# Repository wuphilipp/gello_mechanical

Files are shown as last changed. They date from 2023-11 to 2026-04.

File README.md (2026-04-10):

# GELLO Mechanical
This is the central repo that holds the mechanical parts for GELLO. See the [website](https://wuphilipp.github.io/gello_site/) for the paper and other resources for GELLO.

If you have already built your GELLO, please see the [gello_software repo](https://github.com/wuphilipp/gello_software) for software setup and usage.

## Organization
Currently we support 7 robot types. The 3 from the original paper:
 * Franka FER (from Franka Robotics)
 * UR5 (from Universal Robotics)
 * xArm7 (from uFactory)

And 3 from community contributions:
 * YAM (from I2RT). Contributed by [Jeffrey Liu](https://github.com/jyliu24) and [Hardik Maheshwari](https://github.com/hmahesh007).
 * Lite6 (from uFactory). The lite6 design is contributed from [EL2031watson](https://twitter.com/EL2031watson). See the instructions [here](./lite6/README.md).
 * AR4 (from [Annin Robotics](https://www.anninrobotics.com/)) contributed by [@adob](https://github.com/adob). See instructions [here](./ar4/README.md).
 * FR3 and FR3 Duo (from and contributed by [Franka Robotics](https://franka.de)). See instructions [here](./franka_fr3/README.md)

Each robot has its own folder, with its own robot specific parts. The gripper files are in its own folder, which is shared across robots.
The stls can be printed directly. See the assembly instructions for more detailed instructions.

 * `franka_fer`: contains Franka FER specific parts
 * `franka_fr3`: contains Franka FR3 and FR3 Duo specific parts
 * `ur5`: contains UR5 specific parts
 * `xarm7`: contains xArm7 specific parts
 * `yam`: contains YAM (Yet Another Manipulator) specific parts
 * `lite6`: contains Lite6 specific parts and instructions.
 * `ar4`: contains AR4 specific parts
 * `gripper`: contains the parts for the gripper, which is also shared across robots

## Bill of Materials (BOM) and Assembly Instructions
The BOM and instructions for assembly can be found here: [BOM and Assembly Instructions](https://docs.google.com/document/d/1bdvqPiW4jI5PJm6aIFizhcTuyVJZGEIgqbJe92IoyaM/edit?usp=sharing)

## Notes
If you would like access to the CAD files, please contact me at `phil80301[at]berkeley[dot]edu` .
If you run into any issues during assembly, please open a github issue.

## Contribution
If you have made any improvements to GELLO or made designs for a new robot, please contribute by making a pull request!

# Citation
```
@misc{wu2023gello,
    title={GELLO: A General, Low-Cost, and Intuitive Teleoperation Framework for Robot Manipulators},
    author={Philipp Wu and Yide Shentu and Zhongke Yi and Xingyu Lin and Pieter Abbeel},
    year={2023},
}
```

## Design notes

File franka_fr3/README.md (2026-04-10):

# GELLO for Franka FR3 and FR3 Duo - Assembly Overview

This subfolder contains the 3D-printable parts (STLs) for the **Franka GELLO** and **Franka GELLO Duo**, which are compatible with the Franka FR3 and Franka FR3 Duo robot systems.

This document provides a **high-level assembly overview** describing the structure, topology, and constraints of the system.  
It intentionally avoids detailed, step-by-step instructions.

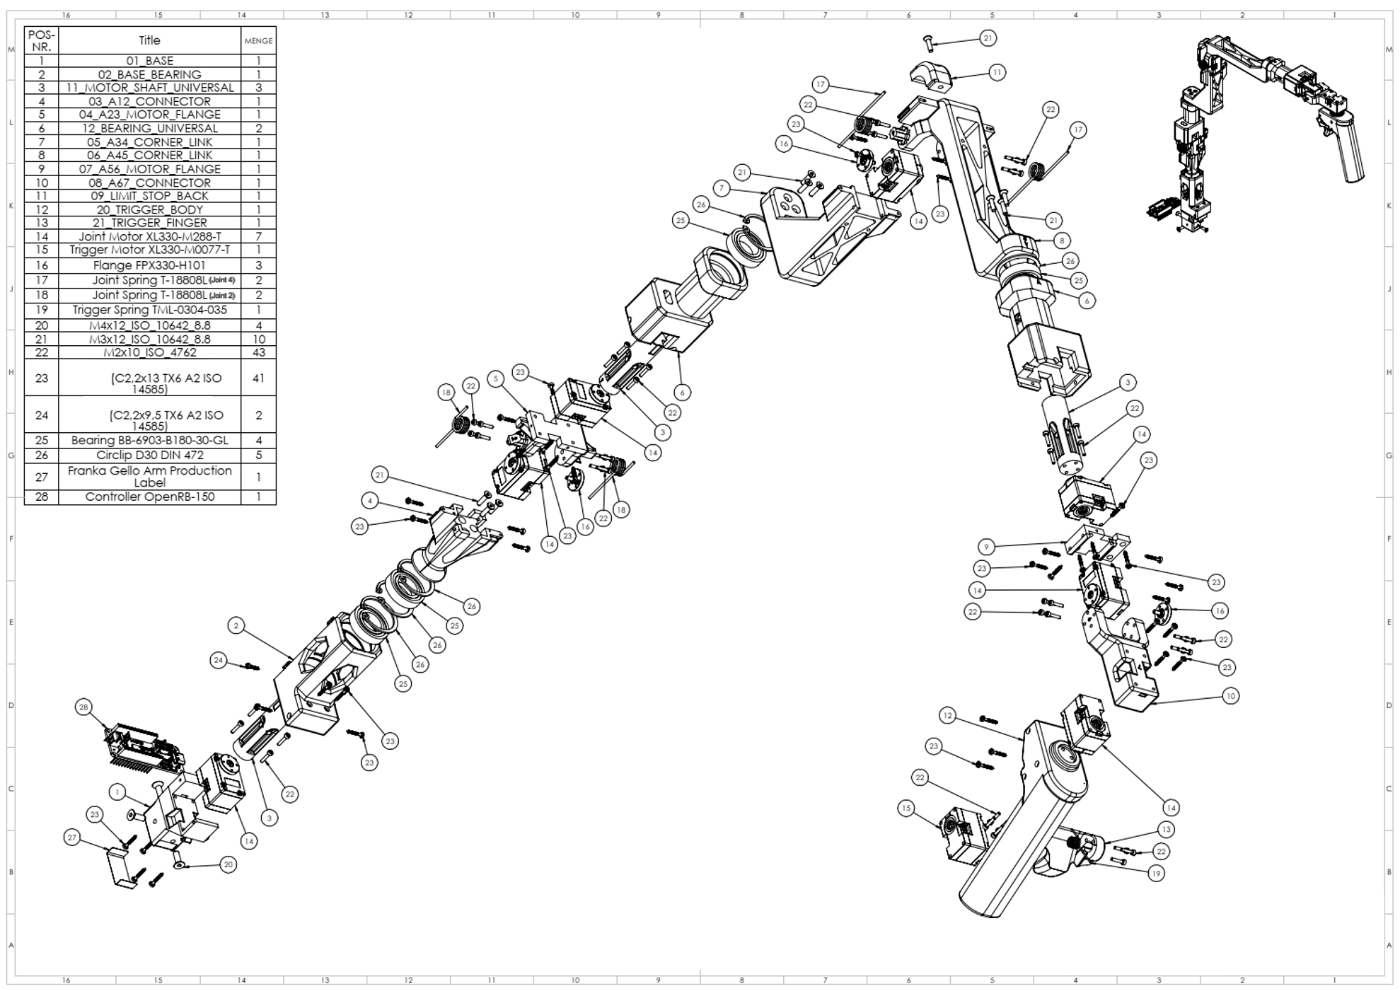
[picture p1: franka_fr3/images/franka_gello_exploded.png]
Exploded Assembly

*Exploded view showing the relationship between individual printed parts, joints, and the base structure.*

---

## What’s Included

- STL files for all structural Franka GELLO arm components
- Bases for single-arm and dual-arm configurations

> ⚠️ Hardware components (actuators, fasteners, bearings, electronics, cabling) are listed in the exploded drawing and must be sourced separately.

---

## Base Variants

The Franka GELLO system supports two base configurations:

### Single Base
- Designed to mount the **Franka GELLO** in a single arm configuration
- Used for standalone or single-robot setups

### Duo Base (FR3 Duo)
- Designed specifically for **FR3 Duo** configurations
- Hosts **two Franka GELLO arms** in a fixed arrangement
- The relative pose between both arms is defined by the base geometry

---

## Assembly Instructions

### Franka GELLO (Single Arm)

**Required 3D printed parts**
- 1x `00_TABLE_BASE_MOUNT_SINGLE.STL`
- 1x `01_BASE.STL`
- 1x `02_BASE_BEARING.STL`
- 1x `03_A12_CONNECTOR.STL`
- 1x `04_A23_MOTOR_FLANGE.STL`
- 1x `05_A34_CORNER_LINK.STL`
- 1x `06_A45_CORNER_LINK.STL`
- 1x `07_A56_MOTOR_FLANGE.STL`
- 1x `08_A67_CONNECTOR.STL`
- 1x `09_LIMIT_STOP_BACK.STL`
- 3x `11_MOTOR_SHAFT_UNIVERSAL.STL`
- 2x `12_BEARING_UNIVERSAL.STL`
- 1x `20_TRIGGER_BODY.STL`
- 1x `21_TRIGGER_FINGER.STL`
- 1x `23_TRIGGER_STORAGE_45.STL`

**Assembly steps:**
1. Build up the arm stack on the base (segments `01` through `09`), following the joint order from base to tip shown in the picture above.

   > **Motor direction:** The motors of joints 2, 4, and 6 can be mounted in two directions. This affects the [`joint_signs` parameter of the publisher configuration](https://github.com/wuphilipp/gello_software/blob/main/ros2/README.md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). Check the exact motor direction in the exploded view to get the same value as the default configuration.

   > **Motor flange orientation:** Each motor flange allows for 4 possible mounting orientations. This affects the [`assembly_offsets` and `gripper_range_rad` parameters of the publisher configuration](https://github.com/wuphilipp/gello_software/blob/main/ros2/README.md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). As described in the publisher's README, use the provided script to determine the values for your specific assembly. When assembling multiple GELLO arms, we recommend to choose the flange orientation consistently.

   > **Thread preparation:** Several attachment points in the 3D-printed parts require threads that are not self-tapping. You must **cut the threads by hand** (e.g., with an M2 or M3 tap, depending on the joint) before inserting screws. Do not force screws into unthreaded holes — this will crack the print.

   > **Cable lengths:** Cable lengths between joints vary along the arm. For the connections between joints 2-3, 5-6, 6-7, 7-8, and to the OpenRB-150, the default cables of 180mm length which come with the motors can be used. For the connections between joints 1-2, 3-4, and 4-5, cables of 360mm length are recommended and need to purchased separately.

2. Insert the arm assembly into the `00_TABLE_BASE_MOUNT_SINGLE.STL` and secure it with screws.
3. Attach `23_TRIGGER_STORAGE_45.STL` to a convenient location on the table base, e.g. a front corner. The 45° angle keeps the trigger accessible and the arm resting securely on the mount when not in use.
4. Mount the OpenRB-150 controller to the table base and daisy-chain the motor cables to it.
5. By factory default, each motor has the same ID. Use the [ID Inspection tool of the Dynamixel Wizard 2.0](https://emanual.robotis.com/docs/en/software/dynamixel/dynamixel_wizard2/#id-inspection) to assign unique IDs to each motor in ascending order from base to gripper (joint 1 = ID 1, ...). 

---

### Franka GELLO Duo (Two Arms)

**Required 3D printed parts**
- 1x `00_TABLE_BASE_MOUNT_DUO.STL`
- 2x `01_BASE.STL`
- 2x `02_BASE_BEARING.STL`
- 2x `03_A12_CONNECTOR.STL`
- 2x `04_A23_MOTOR_FLANGE.STL`
- 2x `05_A34_CORNER_LINK.STL`
- 2x `06_A45_CORNER_LINK.STL`
- 2x `07_A56_MOTOR_FLANGE.STL`
- 2x `08_A67_CONNECTOR.STL`
- 2x `09_LIMIT_STOP_BACK.STL`
- 6x `11_MOTOR_SHAFT_UNIVERSAL.STL`
- 4x `12_BEARING_UNIVERSAL.STL`
- 2x `20_TRIGGER_BODY.STL`
- 2x `21_TRIGGER_FINGER.STL`
- 2x `22_TRIGGER_STORAGE.STL`

**Assembly steps:**
1. Build up each arm stack on its respective side of the Duo base, following the same joint order as the single arm. Make sure to assemble both arms identical and interchangeable.

   > **Motor direction:** The motors of joints 2, 4, and 6 can be mounted in two directions. This affects the [`joint_signs` parameter of the publisher configuration](https://github.com/wuphilipp/gello_software/blob/main/ros2/README.md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). Check the exact motor direction in the exploded view to get the same value as the default configuration.

   > **Motor flange orientation:** Each motor flange allows for 4 possible mounting orientations. This affects the [`assembly_offsets` and `gripper_range_rad` parameters of the publisher configuration](https://github.com/wuphilipp/gello_software/blob/main/ros2/README.md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). As described in the publisher's README, use the provided script to determine the values for your specific assembly. When assembling multiple GELLO arms, we recommend to choose the flange orientation consistently.

   > **Thread preparation:** Several attachment points in the 3D-printed parts require threads that are not self-tapping. You must **cut the threads by hand** (e.g., with an M2 or M3 tap, depending on the joint) before inserting screws. Do not force screws into unthreaded holes — this will crack the print.

   > **Cable lengths:** Cable lengths between joints vary along the arm. For the connections between joints 2-3, 5-6, 6-7, 7-8, and to the OpenRB-150, the default cables of 180mm length which come with the motors can be used. For the connections between joints 1-2, 3-4, and 4-5, cables of 360mm length are recommended and need to purchased separately.
   
2. Insert the two arm assemblies into the `00_TABLE_BASE_MOUNT_DUO.STL` and secure them with screws.
3. Mount two `22_TRIGGER_STORAGE.STL` at the front of the table base such that both arms can rest safely when not in use.
4. Mount the two OpenRB-150 controllers to the table base and daisy-chain the motor cables to them. The left controller serves the left arm and the right controller serves the right arm.
5. By factory default, each motor has the same ID. Use the [ID Inspection tool of the Dynamixel Wizard 2.0](https://emanual.robotis.com/docs/en/software/dynamixel/dynamixel_wizard2/#id-inspection) to assign unique IDs per arm to each motor in ascending order from base to gripper (joint 1 = ID 1, ...). 

---

## Software

The ROS 2 implementation for GELLO with Franka FR3 robots and software-side configuration instructions can be found here:  
[https://github.com/wuphilipp/gello_software/tree/main/ros2](https://github.com/wuphilipp/gello_software/tree/main/ros2)

---

## Safety & Responsibility

This is a **reference design for research and prototyping**.

You are responsible for:
- Mechanical integrity
- Safe hardware selection
- Electrical safety
- Proper testing before operation

---

## License

Refer to the LICENSE file in this subfolder of the repository for usage terms.

---

Happy building 🤖

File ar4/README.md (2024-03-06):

# Annin AR4
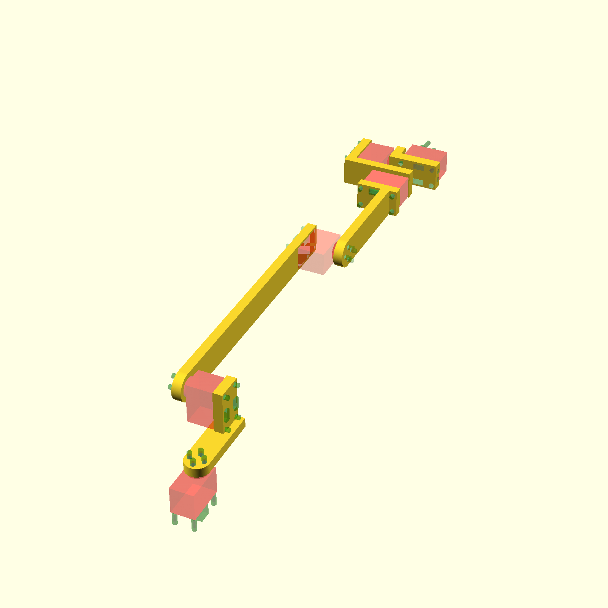
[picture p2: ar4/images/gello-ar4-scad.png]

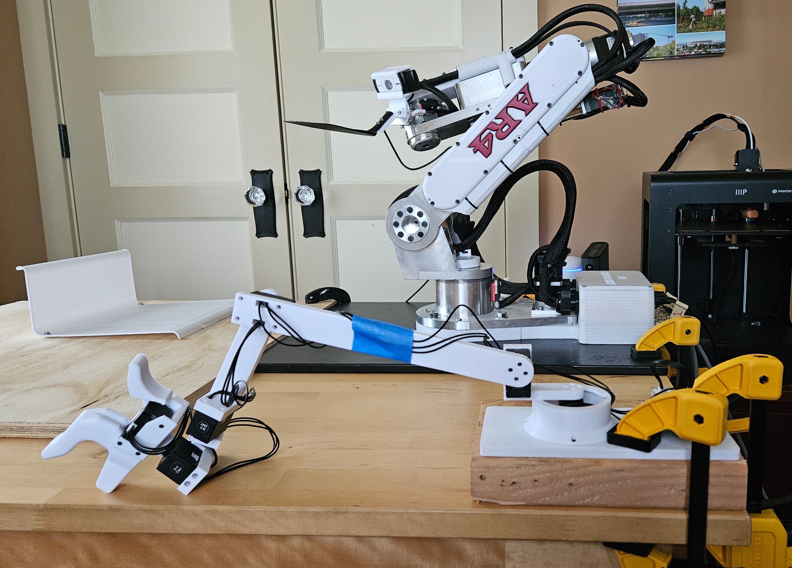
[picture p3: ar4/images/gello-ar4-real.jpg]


GELLO parts for the AR4 series of robotic arms by [Annin Robotics](https://www.anninrobotics.com/).

## BOM

- DYNAMIXEL XL330-M288-T x6 https://www.robotis.us/dynamixel-xl330-m288-t/ 
- DYNAMIXEL XL330-M077-T x1 https://www.robotis.us/dynamixel-xl330-m077-t/ 
- FPX330-H101 x1 https://www.robotis.us/fpx330-h101-4pcs-set/ 
- U2D2 Power Hub Board Set x1https://www.robotis.us/u2d2-power-hub-board-set/ 
- Power Supply x1 https://www.amazon.com/dp/B078RT3ZPS
- Springs (Gripper) x1 https://www.amazon.com/gp/product/B005XQKG4Q

## 3D-printed parts

- [base.stl](3dprint_parts/base.stl)
- [ring.stl](3dprint_parts/ring.stl)
- [l1.stl](3dprint_parts/l1.stl)
- [arm1.stl](3dprint_parts/arm1.stl)
- [arm2.stl](3dprint_parts/arm2.stl)
- [wrist.stl](3dprint_parts/wrist.stl)

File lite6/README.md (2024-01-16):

## UFACTORY Lite 6
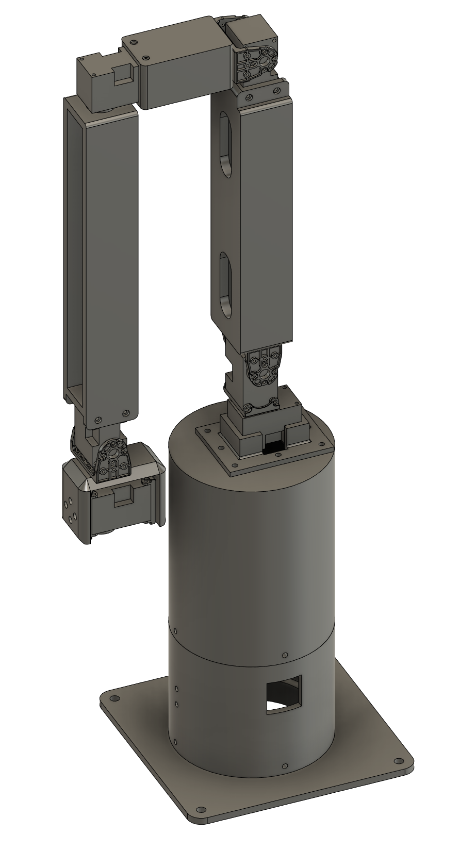
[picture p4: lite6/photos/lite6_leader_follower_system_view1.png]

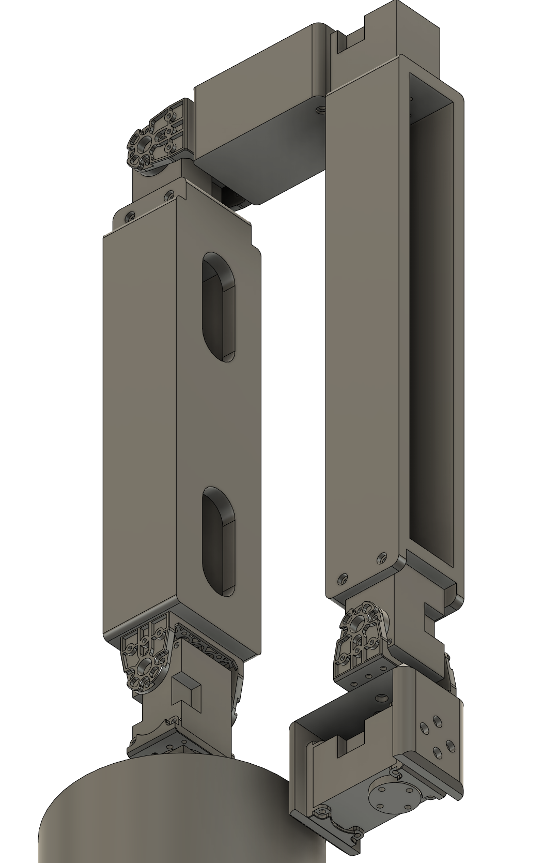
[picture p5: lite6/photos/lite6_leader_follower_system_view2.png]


## BOM
- XL330-M288-T x6 (ROBOTIS https://emanual.robotis.com/docs/en/dxl/x/xl330-m288/)
- FPX330-H101 x3 (ROBOTIS)
- FPX330-S102 x3 (ROBOTIS)

- M2x6mm bolt x 20pcs
- M2 nuts x 20pcs
- U2D2 (ROBOTIS https://emanual.robotis.com/docs/en/parts/interface/u2d2/)
- U2D2 PHB Set (ROBOTIS https://emanual.robotis.com/docs/en/parts/interface/u2d2_power_hub/)

These are included in XL330 servo and FPX330 series:
- M2x6mm screw x a lot
- M2x8mm screw x a lot

## 3D printed parts
- [base.stl](./3dprint_parts/base.stl)
- [L1.stl](./3dprint_parts/L1.stl)
- [L2.stl](./3dprint_parts/L2.stl)
- [L3.stl](./3dprint_parts/L3.stl)
- [L4.stl](./3dprint_parts/L4.stl)

You can also use `base.stl` from the xarm7 folder instead of `base.stl` in this lite6 folder: [base.stl](../xarm7/base.STL)

If you want to keep the height of this leader system the same with the actual Lite 6, prepare these parts:
- [baseRoll.stl](./3dprint_parts/baseRoll.stl)
- [baseRollExtender.stl](./3dprint_parts/baseRollExtender.stl)
- [baseBottom.stl](./3dprint_parts/baseBottom.stl)

## Assembly instruction
- https://www.youtube.com/watch?v=b4JclmGF2Hk

## Contact
https://twitter.com/EL2031watson

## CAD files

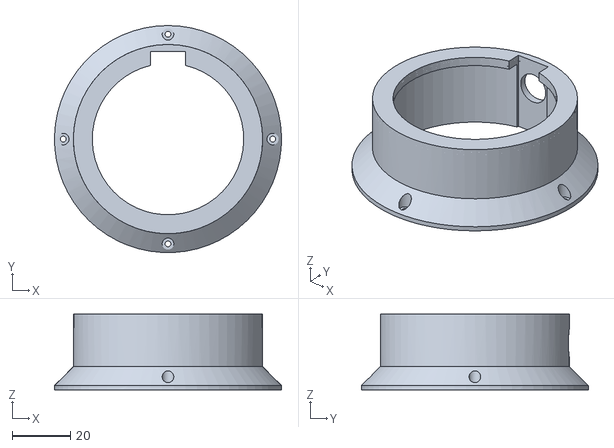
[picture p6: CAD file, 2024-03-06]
ar4/3dprint_parts/ring.stl
78.0 x 77.9 x 26.0

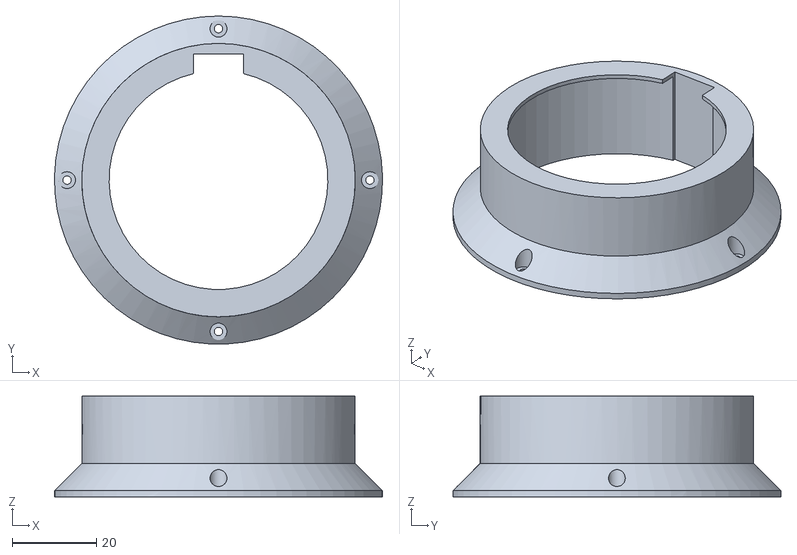
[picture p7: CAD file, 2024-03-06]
ar4/ur5_support_ring.stl
78.0 x 77.9 x 24.0

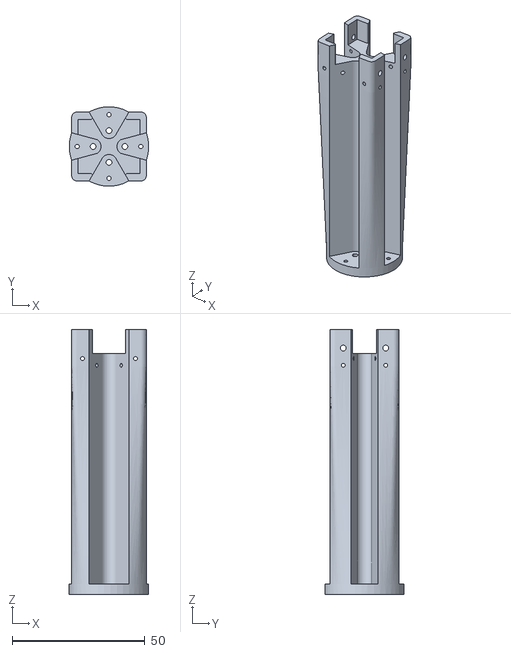
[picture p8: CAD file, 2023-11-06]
franka_fer/L5.STL
30.0 x 30.0 x 100.0

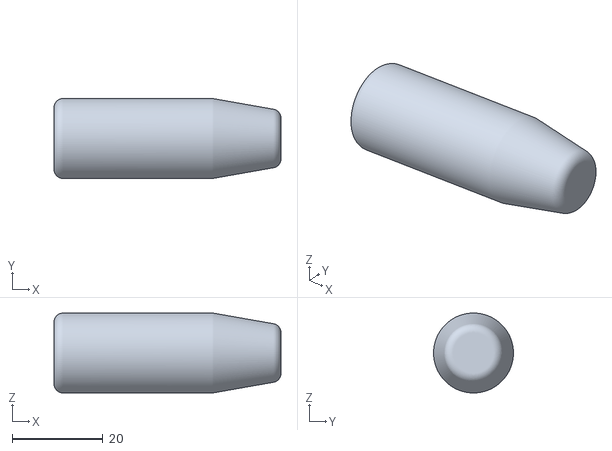
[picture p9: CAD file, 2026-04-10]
franka_fr3/22_TRIGGER_STORAGE.STL
50.0 x 17.6 x 17.6

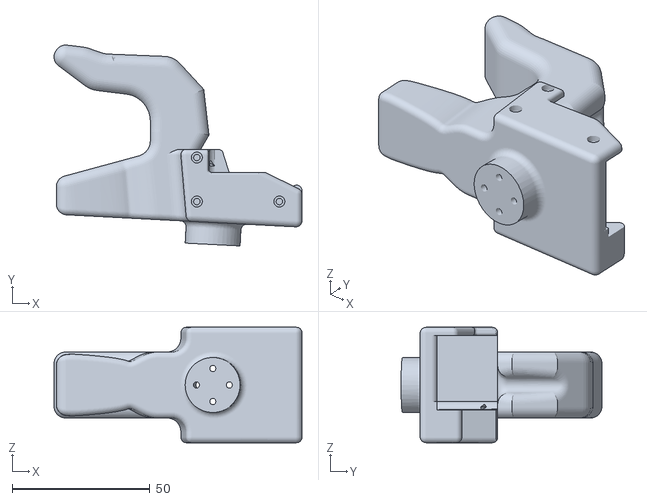
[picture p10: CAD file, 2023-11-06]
gripper/handle.STL
90.2 x 73.1 x 42.0

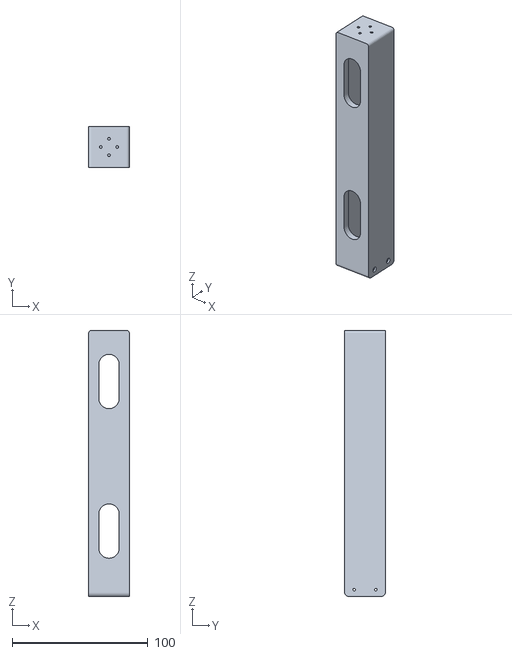
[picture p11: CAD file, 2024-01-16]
lite6/3dprint_parts/L3.stl
30.0 x 30.0 x 195.6

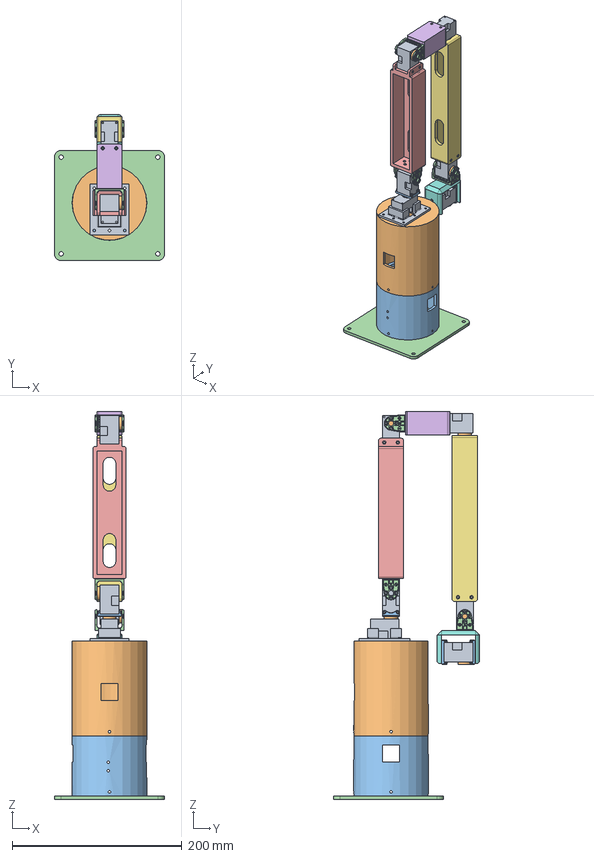
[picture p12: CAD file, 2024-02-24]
lite6/stp/leader_Lite6.step
130.0 x 172.5 x 457.7 mm
ref_XL330 v4 x 6
fpx330-s102 v1 x 3
fpx330-h101 v1 x 3
L1
L2
L3
L4
base
baseRoll
baseRollExtender
baseBottom

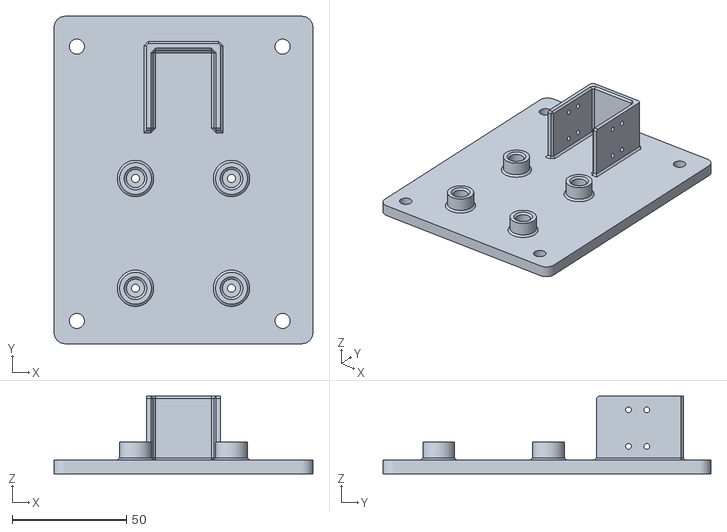
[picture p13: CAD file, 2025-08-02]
yam/GELLO Base.stl
113.3 x 143.3 x 34.0

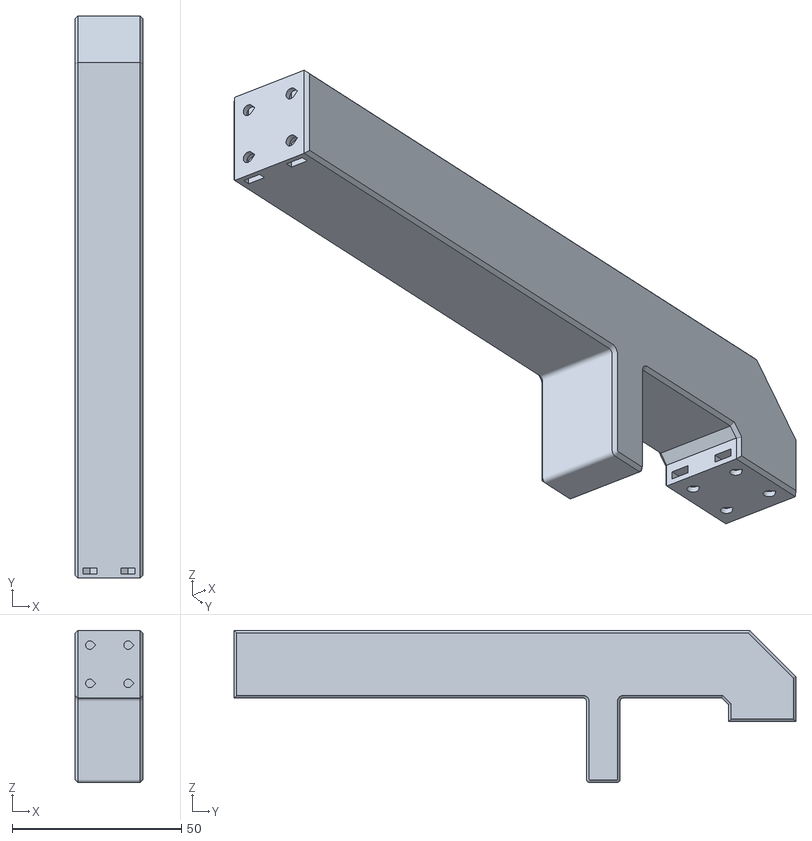
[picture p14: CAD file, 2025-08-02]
yam/yam_active_gello/L3.stl
20.0 x 166.2 x 45.0

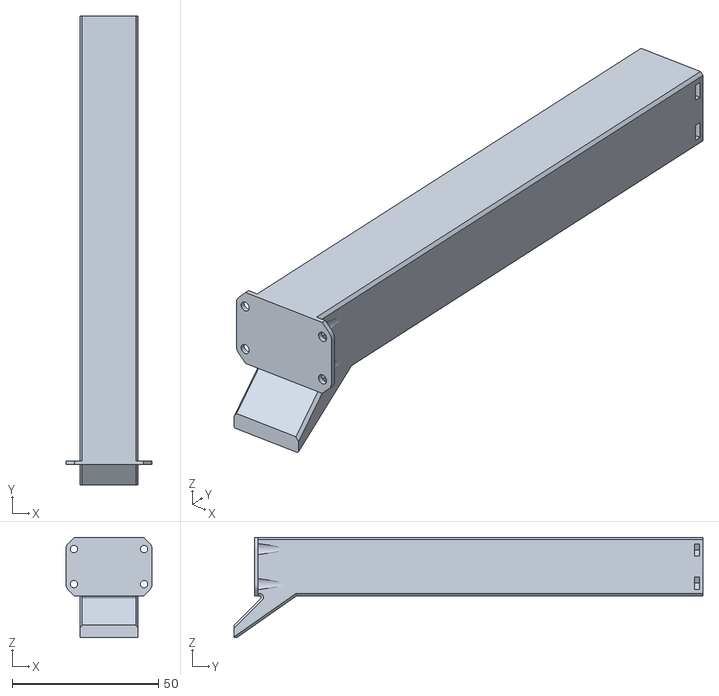
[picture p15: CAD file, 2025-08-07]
yam/yam_passive_gello_large/L1.stl
29.5 x 160.5 x 34.3

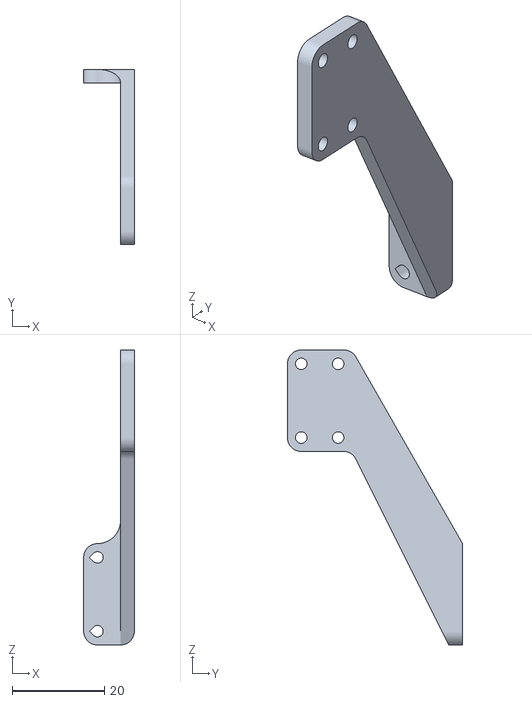
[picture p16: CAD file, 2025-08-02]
yam/yam_passive_gello_small/L4b.stl
11.0 x 38.0 x 64.0

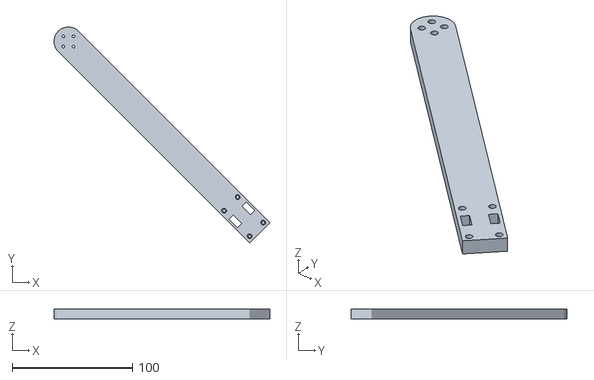
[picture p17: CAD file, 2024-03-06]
ar4/3dprint_parts/arm1.stl
179.6 x 179.6 x 8.00

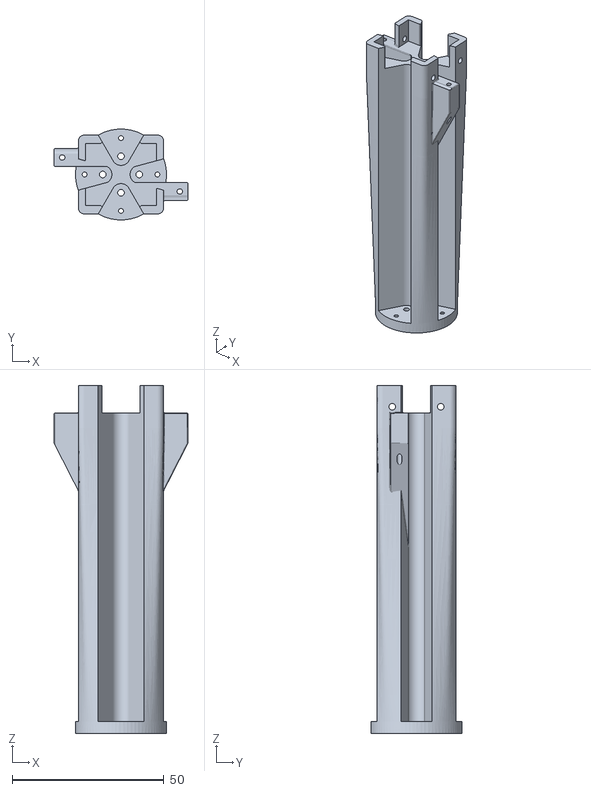
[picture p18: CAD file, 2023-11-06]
franka_fer/L1.STL
44.2 x 30.0 x 114.7

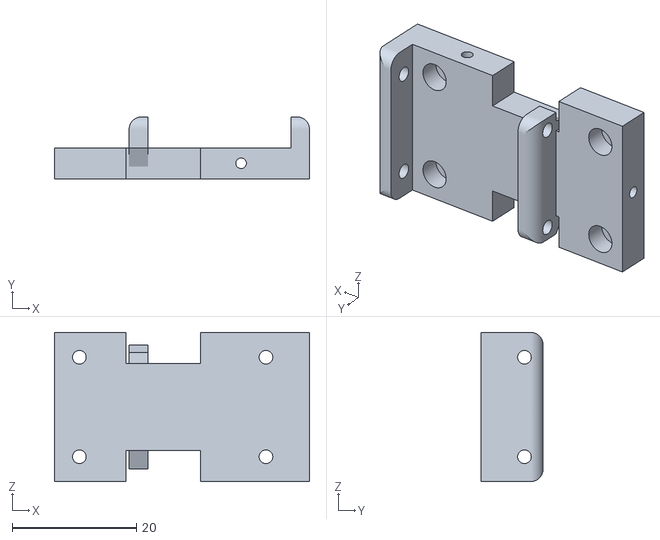
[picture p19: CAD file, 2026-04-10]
franka_fr3/07_A56_MOTOR_FLANGE.STL
41.0 x 10.0 x 24.0

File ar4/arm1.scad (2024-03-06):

$fa = 1;
$fs = 0.4;

use <gello-ar4.scad>;

rotate([180, 0, 45])
arm1();

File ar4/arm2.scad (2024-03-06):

$fa = 1;
$fs = 0.4;

use <gello-ar4.scad>;

rotate([0, 90, 0])
arm2();

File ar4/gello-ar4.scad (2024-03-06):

$fa = 1;
$fs = 0.4;

width = 20;
thickness = 8;

arm_width = width+4;

scale_factor = 0.7;
j2_offset = 64.20*scale_factor;
arm1_length = 305*scale_factor;
arm2_length = 222.63*scale_factor;

dynamixel_width = 20;
dynamixel_length = 34;
dynamixel_height = 23;
dynamixel_full_height = dynamixel_height + 3;
dynamixel_horn_diam = 16;
dynamixel_horn_dist = 1.5;

dynamixel_top_length = dynamixel_horn_diam/2 + dynamixel_horn_dist;
dynamixel_bottom_offset = dynamixel_length - dynamixel_horn_diam/2 - dynamixel_horn_dist;
echo("dynamixel_bottom_offset", dynamixel_bottom_offset);

module borehole() {
    translate([0,0,3.1+50/2]) cylinder(h=50, r=4/2, center=true);
    cylinder(h=100, r=2.35/2, center=true);
}

module horn_borehole(borehole_length=10, borehole_diameter=4) {
    translate([0,0,3.1+borehole_length/2]) cylinder(h=borehole_length, r=borehole_diameter/2, center=true);
    translate([0, 0, 5]) cylinder(h=11, r=2.35/2, center=true);
}

module base_borehole(borehole_length=10, borehole_diameter=4) {
    translate([0,0,1.5+borehole_length/2]) cylinder(h=borehole_length, r=borehole_diameter/2, center=true);
    translate([0, 0, 5]) cylinder(h=11, r=2.35/2, center=true);
}

module l1() {
    padding = 1.5;
    
    difference() {
        linear_extrude(thickness) {
            translate([-width/2, 0, 0])
                square([width, j2_offset+width/2+padding]);
            circle(width/2);
        }

        dynamixel();
    }

    
    
    difference() {
        translate([0, -dynamixel_width/2 + j2_offset, 0])
            translate([-thickness/2, -padding, 0])
            cube([thickness, dynamixel_width+2*padding, dynamixel_length+padding+thickness]);

            translate([-(dynamixel_full_height + thickness/2), j2_offset, dynamixel_length-9.5+thickness])
                rotate([90, 0, -90])
                dynamixel();
    }
}

l1();

module dynamixel(borehole_length=10, horn_rotation=0, borehole_diameter=4) {
    width = 20;
    length = 34;
    height = 23;
    
    horn_height = 3;
    diam = 16;
    horn_dist = 1.5; // distance from top of dynamixel to top horn
    
    translate([-width/2, -(length - diam/2 - horn_dist), -(height+horn_height)])
    color("red", 0.3) {
        cube([width, length, height]);
        translate([width/2, length-diam/2-1.5, 1]) cylinder(h=height+horn_height-1, r=diam/2);
    }
    
    // fasteners
    
    color("green", 0.3) {
        rotate([0, 0, horn_rotation]) {
            translate([6,0,0]) horn_borehole(borehole_length, borehole_diameter=borehole_diameter);
            translate([-6,0,0]) horn_borehole(borehole_length, borehole_diameter=borehole_diameter);
            translate([0,6,0]) horn_borehole(borehole_length, borehole_diameter=borehole_diameter);
            translate([0,-6,0]) horn_borehole(borehole_length, borehole_diameter=borehole_diameter);
        }
        
        translate([dynamixel_width/2-2, dynamixel_top_length-2 ,-dynamixel_full_height]) rotate([180,0,0]) base_borehole(borehole_length);
        translate([-(dynamixel_width/2-2), dynamixel_top_length-2 ,-dynamixel_full_height]) rotate([180,0,0]) base_borehole(borehole_length);
        translate([dynamixel_width/2-2, -((dynamixel_length-dynamixel_top_length)-2) ,-dynamixel_full_height]) rotate([180,0,0]) base_borehole(borehole_length);
        translate([-(dynamixel_width/2-2), -((dynamixel_length-dynamixel_top_length)-2), -dynamixel_full_height]) rotate([180,0,0]) base_borehole(borehole_length);
        
        translate([dynamixel_width/2 - 5/2, dynamixel_top_length-10/2-14, 5-dynamixel_full_height-10]) cube([5, 10, 10], center=true);
        translate([-(dynamixel_width/2 - 5/2), dynamixel_top_length-10/2-14, 5-dynamixel_full_height-10]) cube([5, 10, 10], center=true);
    }
}

// j1
dynamixel();

// j2
translate([-(dynamixel_full_height + thickness/2), j2_offset, dynamixel_length-9.5+thickness])
    rotate([90, 0, -90])
    dynamixel();

module arm1(dynamixels=false) {
    
    difference() {
        linear_extrude(thickness) {
            translate([-arm_width/2, 0, 0])
                square([arm_width, arm1_length+dynamixel_top_length+2]);
                circle(arm_width/2);
        }
        
        translate([0,0,thickness])
            rotate([0,180,0])
            dynamixel();
    
        translate([0, arm1_length, dynamixel_full_height+thickness])
            dynamixel();
    }
    
    if (dynamixels) {
        translate([0,0,thickness])
            rotate([0,180,0])
            dynamixel();
    
        translate([0, arm1_length, dynamixel_full_height+thickness])
            dynamixel();
    }
}

module arm2(dynamixels=false) {
    offset = arm2_length - thickness - dynamixel_full_height - thickness - dynamixel_bottom_offset;
    difference() {
        union() {
            translate([0, 0, -thickness/2])
            linear_extrude(thickness) {
                translate([-arm_width/2, 0, 0])
                    square([arm_width, offset]);
                    circle(arm_width/2);
            }  
            
            translate([0, dynamixel_full_height+thickness+offset, 0]) {
                translate([0, -(dynamixel_full_height+thickness/2), dynamixel_top_length-2])
                cube([arm_width, thickness, dynamixel_length+3], center=true);
                
                if (dynamixels) {
                    rotate([-90, 0, 0])
                        dynamixel();
                }
            }
    
            if (dynamixels) {
                translate([0,0,thickness/2])
                    rotate([0,180,0])
                    dynamixel();
            
            }
            
        } // union
        
        translate([0,0,thickness/2])
            rotate([0,180,0])
            dynamixel();
        
        translate([0, dynamixel_full_height+thickness+offset, 0])
            rotate([-90, 0, 0])
            dynamixel();
    
    }
    
}

module wrist(dynamixels=false) {
    offset = 20;
    wrist_offset = 36.25*scale_factor;
    
    j4_offset = dynamixel_bottom_offset+thickness;
    
    
    
    if (dynamixels) {
        rotate([-90, -90, 0])
        dynamixel();
        
        translate([-(dynamixel_top_length+thickness+2), j4_offset, 0])
        rotate([0, 90, 0])
        dynamixel(horn_rotation=90);
        
        translate([0, j4_offset+wrist_offset, 0])
        rotate([-90, 90, 0])
        dynamixel();
    }
    
    difference() {
        union() {
            translate([-(dynamixel_bottom_offset+dynamixel_full_height-3), 0, -arm_width/2])
            cube([dynamixel_length+dynamixel_full_height-3, thickness, arm_width]);
            
            translate([-(thickness+dynamixel_top_length+2+dynamixel_full_height+thickness), 0, -arm_width/2])
            cube([thickness, dynamixel_length+thickness+1.5, arm_width]);
            
            translate([-(dynamixel_top_length+2)-thickness, wrist_offset-3, -arm_width/2])
            cube([dynamixel_length+1.5+2+thickness, thickness+1.5, arm_width]);
            
            translate([-(thickness+dynamixel_top_length+2), thickness+dynamixel_bottom_offset-dynamixel_horn_diam/2-1.5, -arm_width/2])
            cube([thickness, width, arm_width]);
        }
        
        rotate([-90, -90, 0])
        dynamixel();
        
        translate([-(dynamixel_top_length+thickness+2), j4_offset, 0])
        rotate([0, 90, 0])
        dynamixel(100, horn_rotation=45, borehole_diameter=5);
        
        translate([0, j4_offset+wrist_offset, 0])
        rotate([-90, 90, 0])
        dynamixel();
    }
}


translate([-(thickness+dynamixel_full_height+thickness/2), j2_offset, dynamixel_bottom_offset+thickness])
rotate([0, 90, 0]) {
    arm1(false);
    
    translate([0, arm1_length, thickness+dynamixel_full_height+thickness-thickness/2])
    rotate([0, 180, 0]) 
    union() {
        arm2(true);
        
        offset = arm2_length - thickness - dynamixel_full_height - thickness - dynamixel_bottom_offset;
        translate([0, offset + thickness + dynamixel_full_height, 0])
        rotate([0, 90, 0])
        wrist(true);
    }
}

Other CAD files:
gripper/trigger.STL
lite6/3dprint_parts/baseRoll.stl
yam/yam_active_gello/L4a.stl
ar4/l1.scad
ar4/3dprint_parts/arm2.stl
ar4/3dprint_parts/base.stl
ar4/3dprint_parts/l1.stl
ar4/3dprint_parts/wrist.stl
ar4/ring.scad
ar4/wrist.scad
franka_fer/L2.STL
franka_fer/L3.STL
franka_fer/L4.STL
franka_fer/L6.STL
franka_fer/base.STL
franka_fr3/00_TABLE_BASE_MOUNT_DUO.STL
franka_fr3/00_TABLE_BASE_MOUNT_SINGLE.STL
franka_fr3/01_BASE.STL
franka_fr3/02_BASE_BEARING.STL
franka_fr3/03_A12_CONNECTOR.STL
franka_fr3/04_A23_MOTOR_FLANGE.STL
franka_fr3/05_A34_CORNER_LINK.STL
franka_fr3/06_A45_CORNER_LINK.STL
franka_fr3/08_A67_CONNECTOR.STL
franka_fr3/09_LIMIT_STOP_BACK.STL
franka_fr3/11_MOTOR_SHAFT_UNIVERSAL.STL
franka_fr3/12_BEARING_UNIVERSAL.STL
franka_fr3/20_TRIGGER_BODY.STL
franka_fr3/21_TRIGGER_FINGER.STL
franka_fr3/23_TRIGGER_STORAGE_45.STL
lite6/3dprint_parts/L1.stl
lite6/3dprint_parts/L2.stl
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

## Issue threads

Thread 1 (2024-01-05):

Support for ViperX 300 robot arms

sirwart, 2024-01-05:
I’m attempting to replicate some of the ALOHA results but wanted to use a gello arm to save on cost. Do you have any plans to support the ViperX or pointers if I wanted to try to add support myself?

wuphilipp, 2024-01-08:
I currently don't have plans to add support for the ViperX arm (as ALOHA already does this). However if you are interested in making a GELLO for the ViperX, I'm happy to help support and provide CAD of the existing GELLO arms. Please drop me an email if you are interested!

Closed 2024-01-08.

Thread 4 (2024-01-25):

About 3D Printed Parts

ruanjinchen, 2024-01-25:
Is it convenient for you to provide the model in SolidWorks part format, because we would like to modify the model you posted, thank you very much！🙏🙏

wuphilipp, 2024-01-27:
please drop me an email!

ruanjinchen, 2024-01-27:
ruanjinchen@foxmail.com
THANKS!!!!!🫡

ShangQingLiu, 2024-03-21:
Hi, Thank you for your brilliant work, I would also like to have the model in SolidWorks part format which for creating my own one for Diana-7 Arms.  Here is my mail: shang-ching.liu@uni-hamburg.de

weixiang-smart, 2024-06-27:
Thank you for your excellent work! I would like to design a controller for UR3 in SolidWorks. I would appreciate it if you could share the models. Thank you so much in advance. My email is liangweixiang89@gmail.com

Cheney-36, 2024-07-23:
Thank you for sharing the content. I would like to modify the UR5 model to fit my installation base. If you could share the model, I would greatly appreciate it. My email is cy1440224730@gmail.com

wuphilipp, 2024-07-24:
Hi, thanks for you interested in this project!

In the future for others please email me directly (you can find it on my website https://wuphilipp.github.io/) since I don't check this thread (its already closed).

Have just sent out the files to those of you who asked here.

Have fun and looking forward to what you all build!

Closed 2024-01-27.

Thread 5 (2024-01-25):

Missing circular support base part in UR5 model

adob, 2024-01-25:
The circular support ring seems to be missing from the UR5 STL files. For clarity, this part appears at the bottom, connected to the base in the final render.

wuphilipp, 2024-01-27:
Sorry about that! The ring was remove in the final release. I will update the image to avoid future confusion

Closed 2024-01-27.

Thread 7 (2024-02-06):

Assembly of Franka 3D parts. Which axis to mount the motor horn on

Harimus, 2024-02-06:
Hi! Firstly I want to thank you for the effort and the great work on GELLO!

I'm currently trying to assemble the FRANKA arm component, with all the servos and 3d printed parts. I noticed it was a bit unclear (and hard to see from the FRANKA assembled picture in the google doc manual) which axis I should mount the Servo motor horn on?

Specifically Mounting between L1 & L2,  L3&L4,  L5 & L6. Does it matter _which side_ the motor horn is mounted on, since each joint have two potential places to put the screws in.  I'm kinda trying to do it while checking how the franka arms joints are constructed, but it is a bit confusing, and checking at the parts for xArm and Ur5 they seem to not have this design.

For reference, the picture below is between L1&L2 (sry for 3D printing residuals). Is the mounting horn oriented in the right way or is it supposed to be reverse? Does it even matter? (Is it just a matter of converting the sign of axis later in the calibration/configuration?)
![Uploading PXL_20240206_074146596.MP.jpg…]()

Harimus, 2024-02-08:
I think I solved it any way.

For other people checking this: 1. The picture is wrong, I forgot to add the rotating component from FPX330-H101 on the opposite end of servo-horn.   2. Although the 2 of the servo motors ended up being assembled in the opposite direction (joint 2 and 4) this could be compensated by changing the signs while calibrating the `gello_software`, by changing the `--joint-signs` command line argument when running `scripts/gello_get_offset.py` according to the README.

The README one was Panda: `1 -1 1 1 1 -1 1`, but the correct one for me was `1 1 1 -1 1 -1 1` and it was easy to check by running the simulation and checking when it goes the opposite way.

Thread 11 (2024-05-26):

AR4 base STL file is empty

boyentenbi, 2024-05-26:
@adob , I know it's fairly simple, but the STL file for the base of your AR4 gello is empty, would you be able to upload it? :)

Thanks,
Peter

adob, 2024-05-26:
The base STL file (ar4/3dprint_parts/base.stl) should be a symbolic link to
../../ur5/base.STL. Is that not the case?

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

boyentenbi, 2024-05-26:
Ah that's right, thanks for clarifying.

Closed 2024-05-26.

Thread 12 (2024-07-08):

Replace M288 Servos with M077 Servos. Servos are only being used for their encoders, so does their torque even matter?

jmcoholich, 2024-07-08:
We are planning to build the Gello device for Franka, which requires 7x M288 servos.

The DYNAMIXEL website states that there is a 3-4 lead time for these: https://www.robotis.us/dynamixel-xl330-m288-t/
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

Is it possible to replace the M288s with M077 servos, which currently have no such lead time? It looks like the servos are identical in every aspect except their stall torque/rpm ratings. I believe this shouldn't even matter, since the servos are only being used for their encoders.

hygradme, 2024-07-23:
You can use M077 instead of M288. Sometimes,  I also use M077 for the joints near end effector to reduce the friction caused by higher reduction ratio gears and realized smooth joint movements.
But higher friction sometimes help more stable manipulation especially for the joints near the base of the arm where the effect of the gravity of the servos and other parts are higher and you need to resist against it. The higher friction reduces the gravity effect.

Also, you can try XC330-M288-T or XC330-M181-T if you have enough budgets.

jmcoholich, 2024-07-23:
Makes sense, thanks!

Closed 2024-07-23.

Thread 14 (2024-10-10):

Using Gello as a manipulator

Jendker, 2024-10-10:
Hi,

I really like Gello’s clean design and am considering customizing it to use the arm as a manipulator. Based on what we already know, do you anticipate any potential issues with this approach?

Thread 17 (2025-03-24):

STEP/STP files request - standard CAD open source format

pilcsimo, 2025-03-24:
Hello,

I'd like to add an alternative design of the gripper and Franka assembly. I would like to request step/stp files which are the go-to format for CAD software.
### Issue:
As I am from the EU, I cannot source the springs that should be added to the Franka teleoperation device and so it sags/falls over when extending the arm, which is very dangerous when real-time teleoperating. As a result of the springs missing the gripper doesnt return to the open position.
### Proposed solution:
I devised a plan to implement 3D printable, print-in-place, compliant springs that would replace the ones in the BoM. As FDM 3D printers are not precise enough to print a replacement spring of the same dimensions as the metal springs in the BoM, this will require clever design utilising the GELLO project as the reference/starting point.
### Request
I use Fusion 360 for this and I would like to ask you to add the files in some sort of CAD format such as STEP/STP. I know STLs are just fine for 3D printing in most cases, but do not suffice when it comes to any sort of model editing as they are just polygon mesh files.
### In return
I will provide eveything I designed as open-source, in a fork of this repo or my own where I will link GELLO as the basis. This will make GELLO even more accessible for the EU for example.

Thank you in advance for your response.

Closed 2025-08-27.

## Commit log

2023-11-06 add stl files
    [L1.STL, L2.STL, L3.STL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]
2024-01-13 add lite6 version
    [L1.stl, L2.stl, L3.stl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]
2024-01-13 fix stl to STL for xarm7 base link
2024-02-23 add stp file for UFACTORY Lite 6 leader
    [leader_Lite6.step]
2024-03-06 Add mechanical parts for the Annin AR4 arm (#6)
    * ar4 support
    * add ar4 picture
    [arm1.scad, arm1.stl, arm2.scad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]
2025-08-02 Add passive and active YAM Gello (#20)
    * updates
    * stls
    * files
    * files
    * minor
    * files
    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
    [GELLO Base.stl, L1.stl, L2.stl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]
2025-08-07 Added YAM GELLO gripper body and fixed link 1 (#21)
    * YAM gripper and new L1
    * Update README.md
    ---------
    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
    [L1.stl]
2025-11-08 Revise assembly instructions to include BOM
    Updated the section to include Bill of Materials and revised the link for assembly instructions.
2026-04-09 Adding Franka GELLO and Franka GELLO Duo
    [00_TABLE_BASE_MOUNT_DUO.STL, 00_TABLE_BASE_MOUNT_SINGLE.STL, 01_BASE.STL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]
